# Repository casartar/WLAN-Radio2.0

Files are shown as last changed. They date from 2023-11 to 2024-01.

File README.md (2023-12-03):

# WLAN-Radio2.0

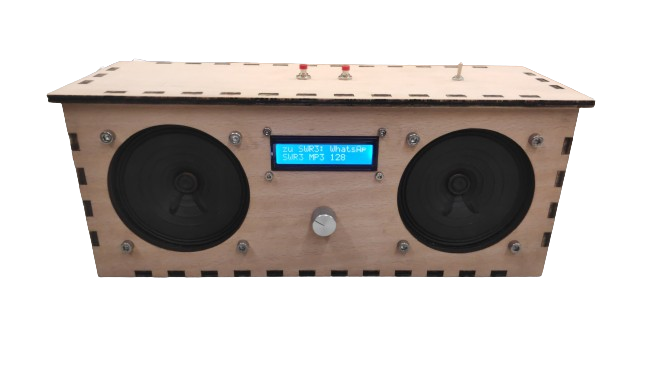
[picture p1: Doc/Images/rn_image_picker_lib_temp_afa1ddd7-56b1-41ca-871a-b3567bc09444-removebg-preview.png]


## 1. Komponenten
TBD

## Testaufbau
### SMD Bestückung
Siehe [ibom](https://github.com/casartar/WLAN-Radio2.0/blob/main/Hardware/WLAN-Radio-HAT/bom/ibom.html)
### THT Bestückung

Buchsenleiste an WLAN-Radio-HAT anlöten. Darauf auchten, dass der Stecker gut auf der Platine aufliegt.

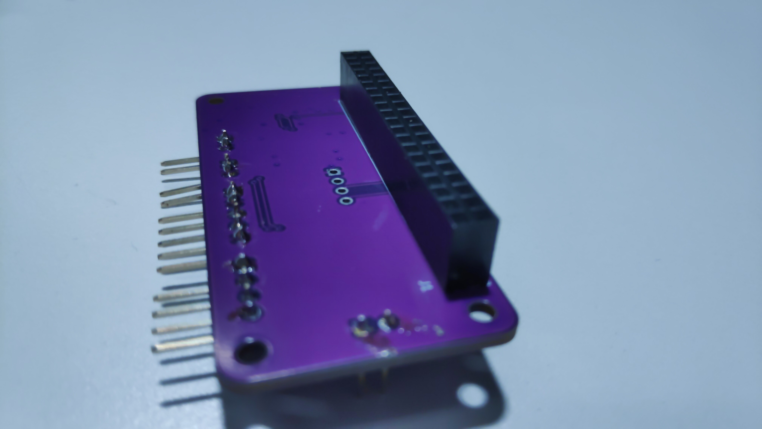
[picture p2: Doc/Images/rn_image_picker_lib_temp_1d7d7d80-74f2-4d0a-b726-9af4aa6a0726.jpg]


Gewinkelte Stiftleisten anlöten.

Aus Gründen für die 5V Spannungsversorgung gerade Stiftleisten verwenden.

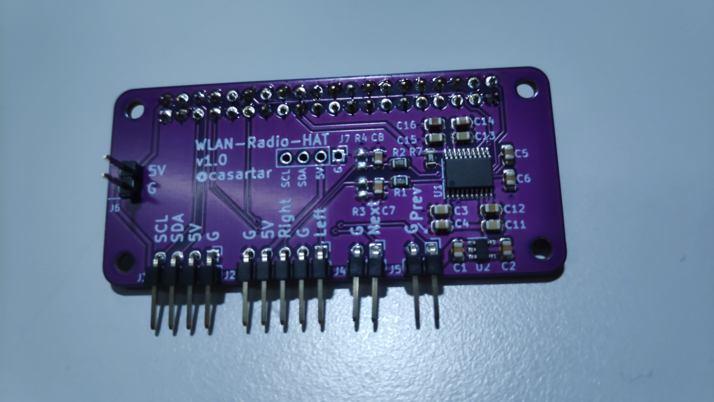
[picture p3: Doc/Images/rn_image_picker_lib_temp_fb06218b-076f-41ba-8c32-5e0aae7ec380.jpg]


Buchsenleiste and LCD anlöten.

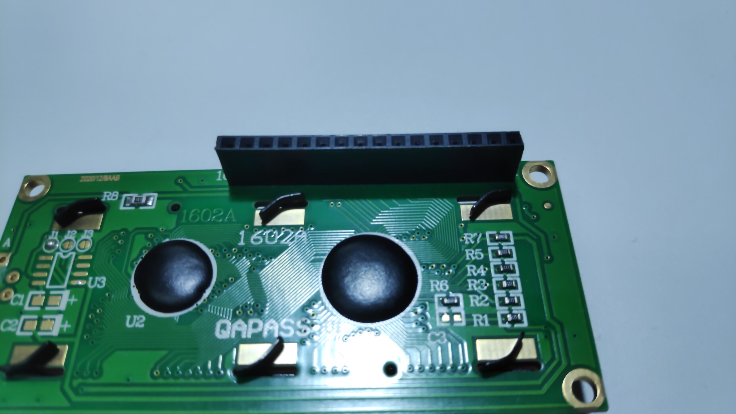
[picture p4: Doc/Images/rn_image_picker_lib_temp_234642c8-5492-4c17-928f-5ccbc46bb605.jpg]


Gewinkelte Stifleisten an Verstärkermodul anlöten.

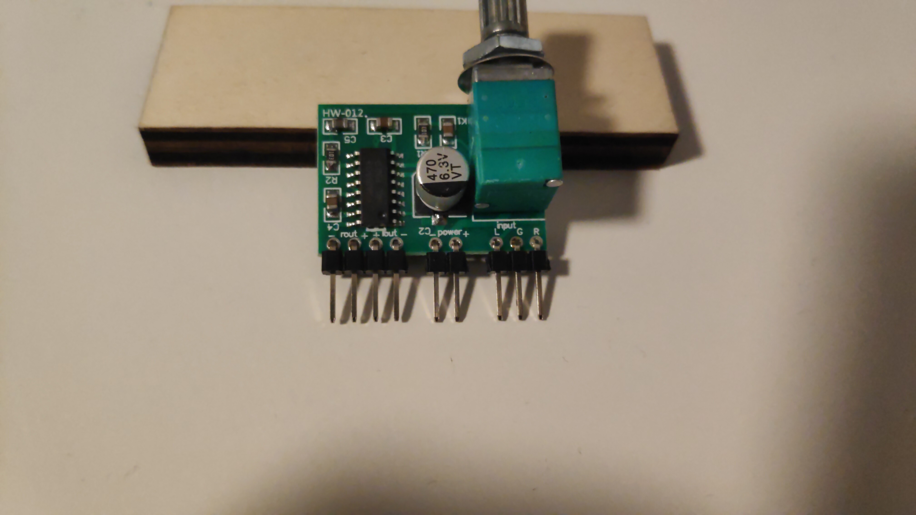
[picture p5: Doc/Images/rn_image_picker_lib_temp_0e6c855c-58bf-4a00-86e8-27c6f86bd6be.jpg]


### Testaufbau

* WLAN-Radio-HAT auf Raspberry Pi Zero W stecken.
* LCD anschließen.
* Verstärker anschließen.
* Lautsprecher an Verstärker anstecken.
* Micro-USB-Kabel an das Raspberry Pi anschließen (PWR IN).

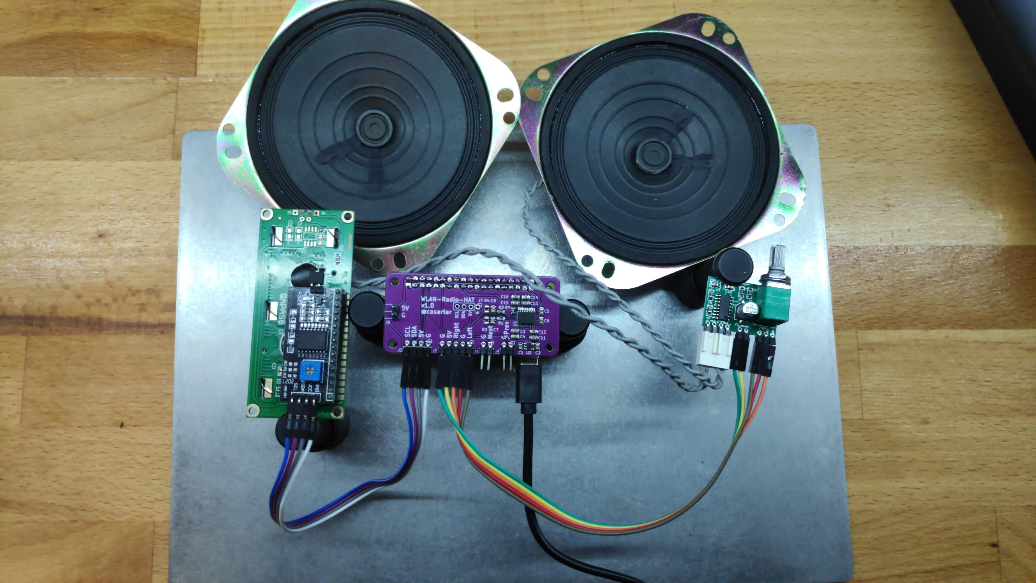
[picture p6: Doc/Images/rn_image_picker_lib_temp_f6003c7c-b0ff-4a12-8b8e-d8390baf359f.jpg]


## Software-Installation

### Erstellen der SD-Karte für den Raspberry Pi mittels Raspberry Pi Imager

Raspberry Pi Imager installieren - https://www.raspberrypi.com/software/ 

Raspberry Pi Imager ausführen.
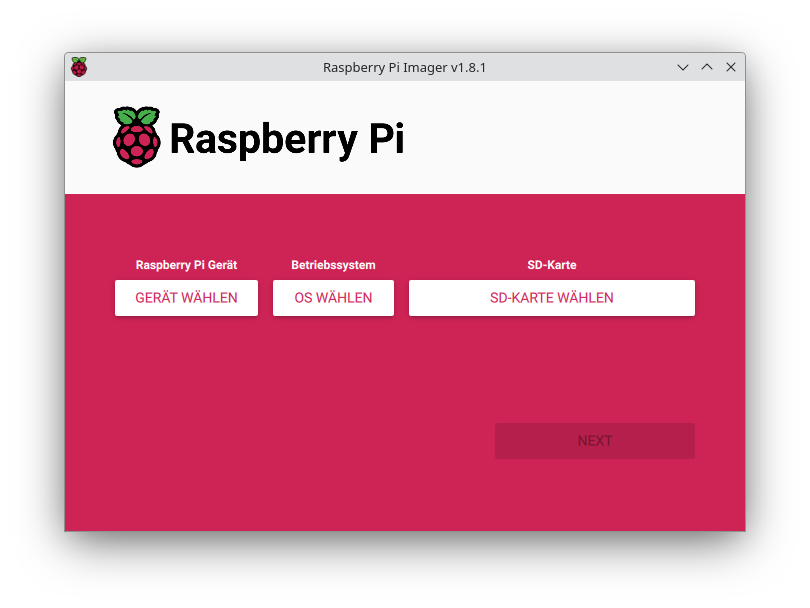
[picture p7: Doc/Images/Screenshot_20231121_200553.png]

Gerät wählen: Raspberry Pi Zero
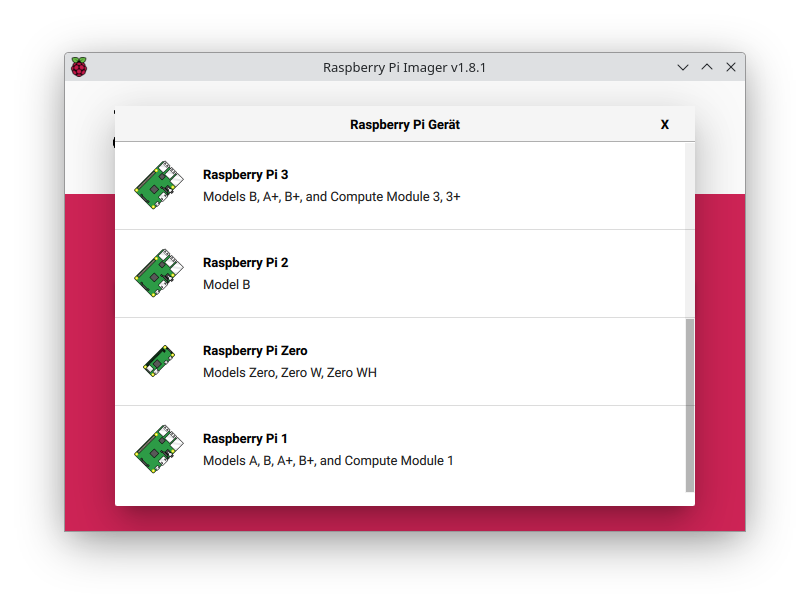
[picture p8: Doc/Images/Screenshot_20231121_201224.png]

Os wählen: Raspberry Pi OS (other)
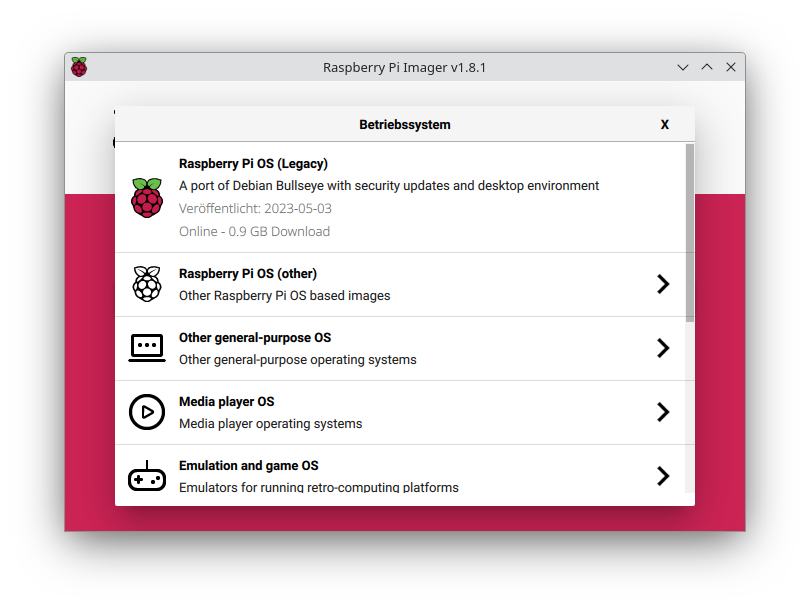
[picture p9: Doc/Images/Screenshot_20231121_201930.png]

Raspberry Pi OS (Legacy) Lite
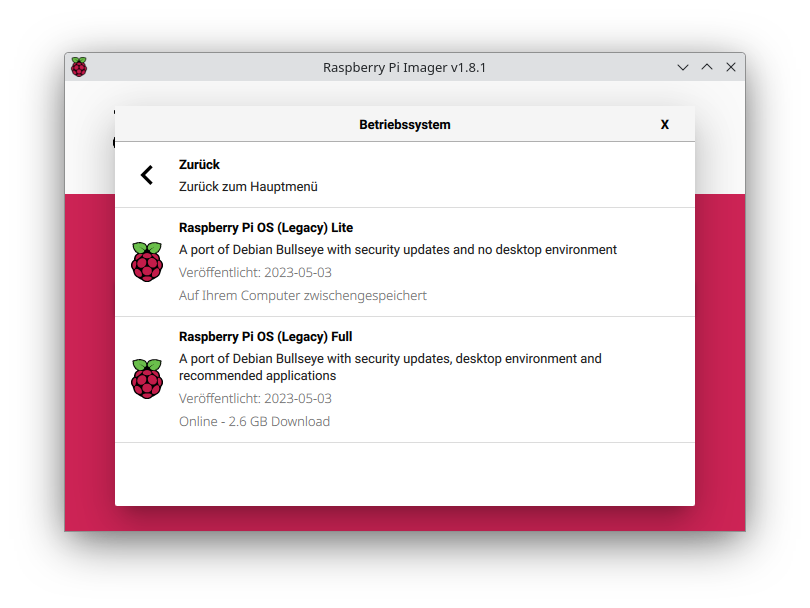
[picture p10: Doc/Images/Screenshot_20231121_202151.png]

SD-Karte wählen.
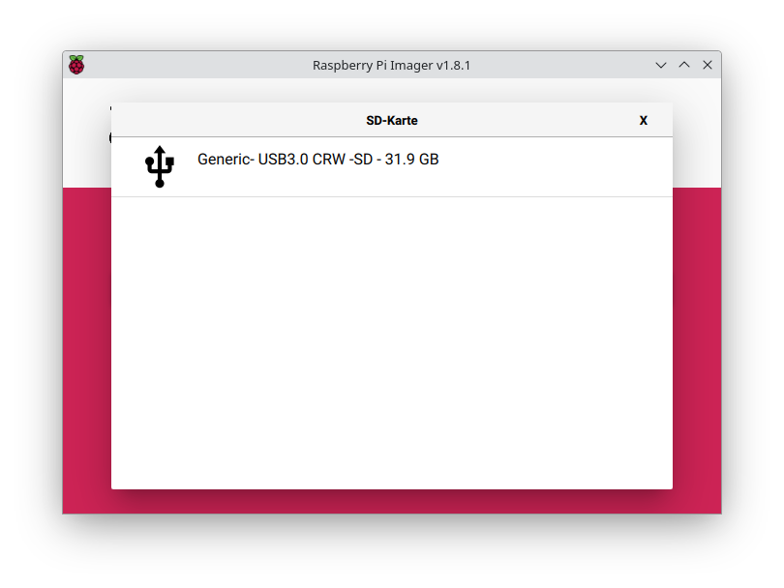
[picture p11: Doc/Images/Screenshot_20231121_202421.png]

Next
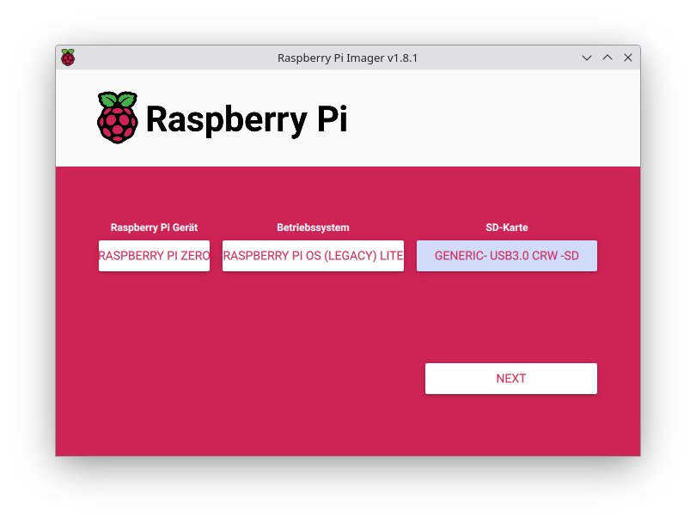
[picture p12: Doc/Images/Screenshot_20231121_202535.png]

Einstellungen bearbeiten.
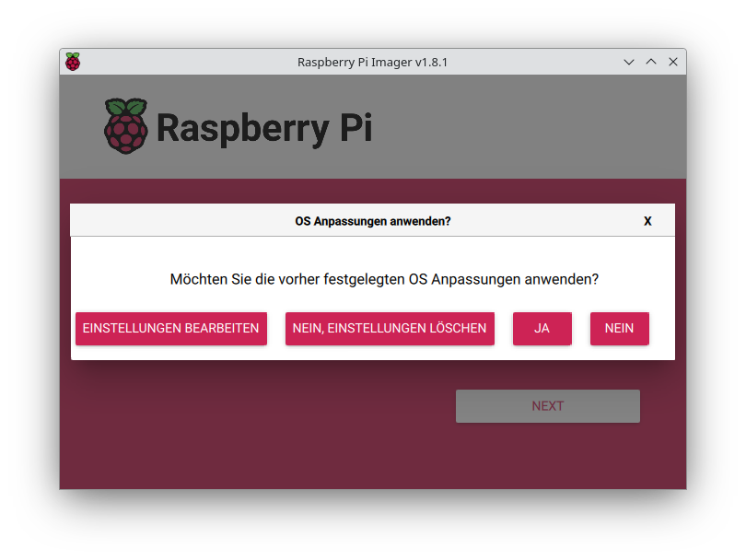
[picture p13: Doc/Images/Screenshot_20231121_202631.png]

* Hostname: individuell benennen.
* Benutzer: "pi"
* Passwort: "raspberry"
* SSID: geheim
* Passwort: geheim

Im Reiter "Dienste" kann man auch gerne seinen Public Key hinterlegen, muss aber nicht sein.
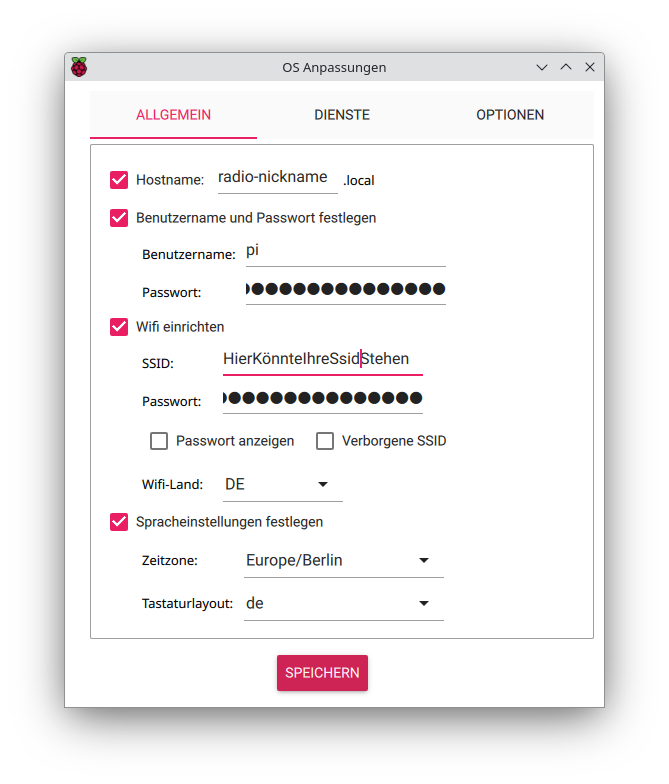
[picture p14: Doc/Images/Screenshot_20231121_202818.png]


Im Reiter "Dienste" SSH aktivieren und "Passwort zur Authentifizierung verwenden" auswählen. Wer weiß was er tut, kann man auch gerne seinen Public Key hinterlegen, muss aber nicht sein.
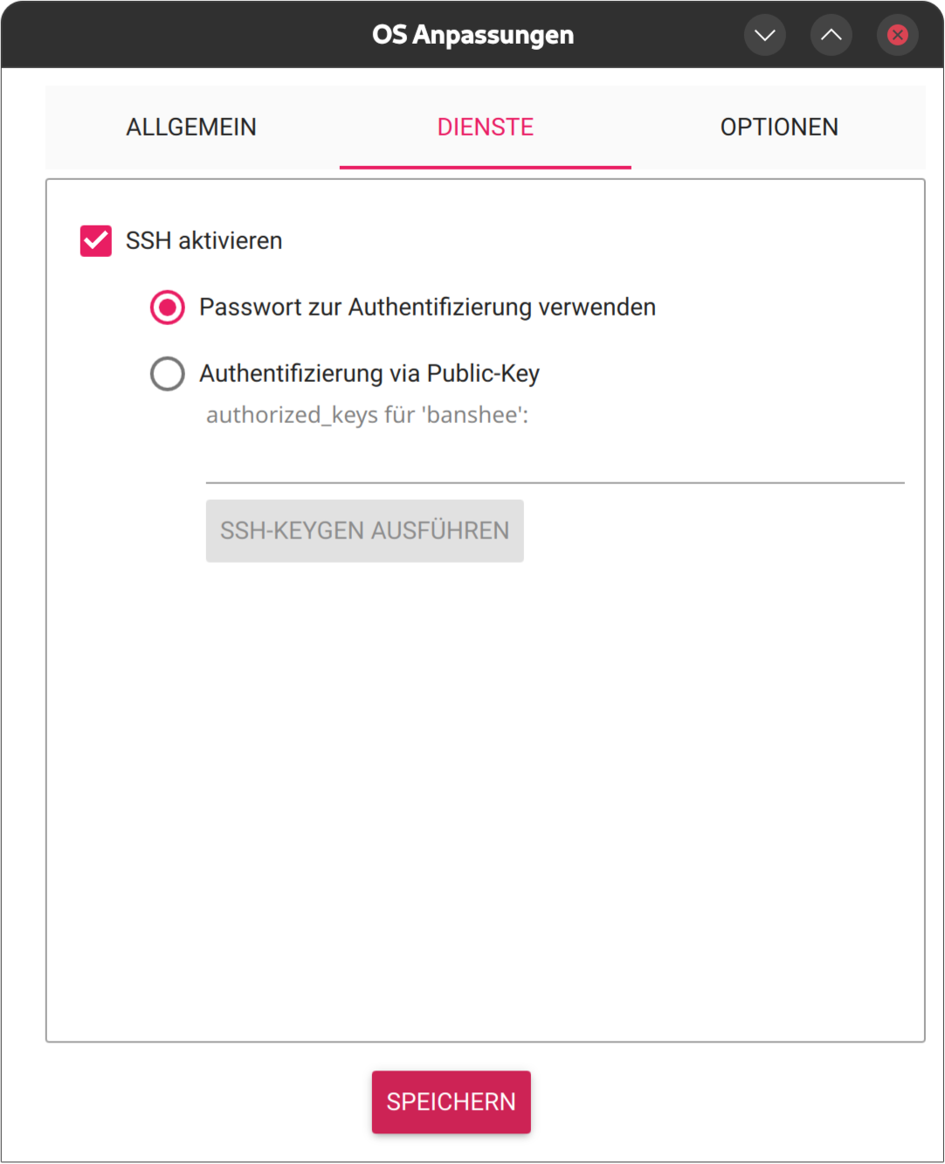
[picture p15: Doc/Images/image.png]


Speichern und Ja wählen und mit Ja bestätigen
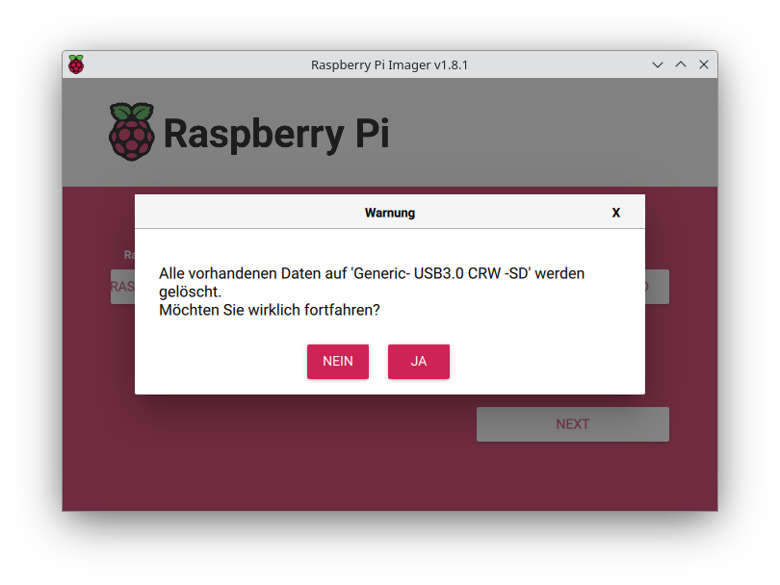
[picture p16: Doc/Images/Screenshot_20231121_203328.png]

SD-Karte wird beschrieben.
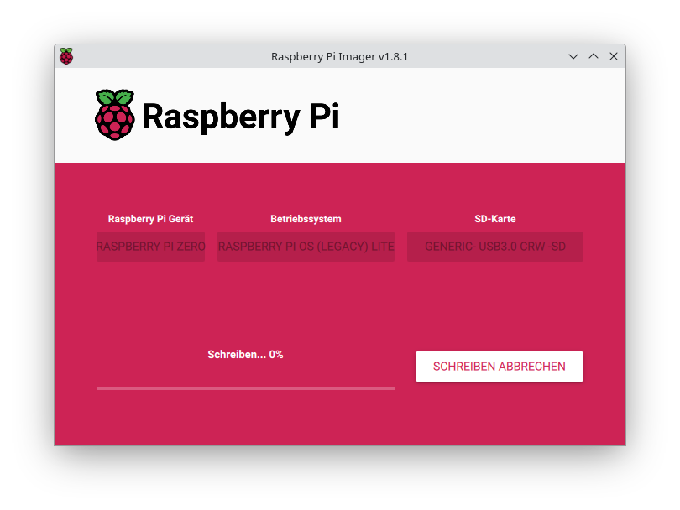
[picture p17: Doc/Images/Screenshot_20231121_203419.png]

SD-Karte ist fertig beschrieben.
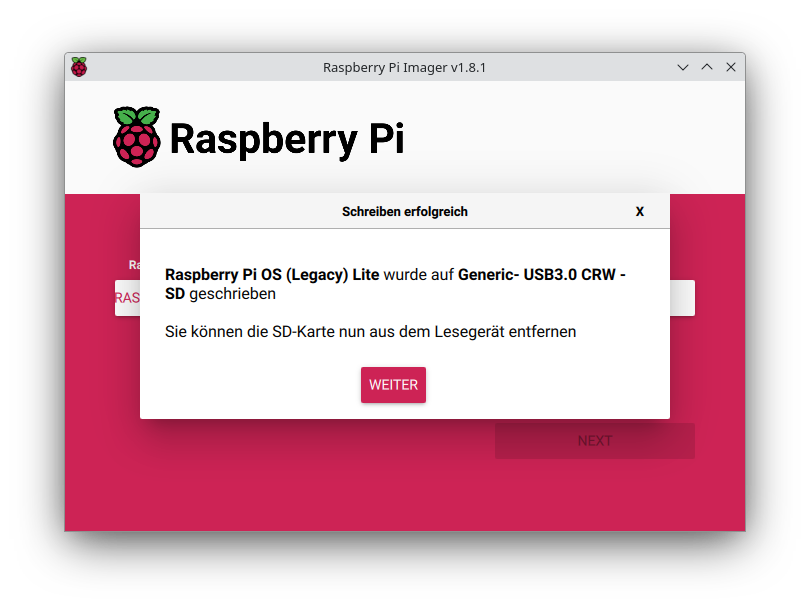
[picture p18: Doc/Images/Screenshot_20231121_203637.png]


SD-Karte in Pi einstecken und Micro-USB-Kabel an Laptop anschließen.
  
### Der erste Start des Pi dauert u.U. mehrere Minuten

### System aktualisieren
IP Adresse herausfinden

Verbinden per ssh, user: pi; passwort wie oben konfiguriert.
Der Befehl funktioniert unter Linux und unter Window in der PowerShell

```
ssh pi@xxx.xxx.xxx.xxx

sudo apt update
sudo apt upgrade
```

### GIT installieren und WLAN-Radio2.0 clonen

```
sudo apt install git
sudo git clone https://github.com/casartar/WLAN-Radio2.0.git
```

### LCD Komponenten installieren und Testen

```
sudo apt install i2c-tools
sudo apt install python3-pip
sudo apt install python3-smbus
pip install RPLCD
```
Wenn pip einen Fehler ausgibt noch mal versuchen mit:
```
pip install RPLCD --break-system-packages
```

/boot/config.txt anpassen mit

```
sudo nano /boot/config.txt
```

Parameter: **dtparam=i2c_arm=on** einkommentieren

Speichern mit Strg+O, Enter und Schließen mit Strg+X.

Neustart

```
sudo reboot
```

Verbinden per ssh

```
sudo i2cdetect -y 1
cd ~/WLAN-Radio2.0/Software
python3 lcd_test.py
```

Auf dem LCD sollte jetzt **"WLAN Radio"** und **"1234567890abcdef"** angezeigt werden.

### Audio Komponenten installieren und Testen

/boot/config.txt anpassen mit

```
sudo nano /boot/config.txt
```

Am Ende der Datei hinzufügen: **dtoverlay=hifiberry-dac**
Zeile auskommentieren (Raute vorne dran) **#dtparam=audio=on**
Zeile auskommentieren (Raute vorne dran)  **#dtoverlay=vc4-kms-v3d**

Speichern mit Strg+O, Enter und Schließen mit Strg+X.

Neustart

```
sudo reboot
```

Verbinden per ssh

Testen mit:

```
speaker-test -t wav -c 2
```

Es sollte "Front Left" und "Front Right" aus den entsprechenden Lautsprechern ertönen.

Mit Strg + C kann die Ausgabe abbrechen.

### MPD und MPC einrichten (Music Player Daemon, Music Player Client)

```
sudo apt install mpd
sudo apt install mpc
```

/etc/mpd.conf anpassen mit

```
sudo nano /etc/mpd.conf
```

Zeile ändern von
```
playlist_directory   /var/lib/mpd/playlists
```
in
```
playlist_directory   /home/pi/Playlists/
```

und 

```
audio_output {
#       type            "alsa"
#       name            "My ALSA Device"
#       device          "hw:0,0"        # optional
#       mixer_type      "hardware"      # optional
#       mixer_device    "default"       # optional
#       mixer_control   "PCM"           # optional
#       mixer_index     "0"             # optional
}
```
ändern in 

```
audio_output { 
        type            "alsa" 
        name            "sysdefault:CARD=sndrpihifiberry" 
        mixer_type      "software" 
}
```

Speichern mit Strg+O, Enter und Schließen mit Strg+X.

Das Verzeichnis anlegen: 
```
mkdir ~/Playlists
```

Default Playlist aus dem Repo in dieses Verzeichnis kopieren: 

```
cp ~/WLAN-Radio2.0/Playlist/Playlist.m3u Playlists/
```

mpd.service neu starten: 
```
sudo systemctl restart mpd
```
Testen ob Radio abgespielt wird
```
mpc load Playlist
mpc play
mpc next
mpc status
mpc pause
```
Wenn nach mpc load P Playlist nicht autovervollständigt wird, muss evtl. in der mpd.conf der User von mpd zu pi geändert werden.

MPD Library installieren
```
sudo apt install python3-mpd
```
MPD Test Script ausführen
```
cd ~/WLAN-Radio2.0/Software
python3 mpd_test.py
```

Es sollte ein Sender abgespielt werden.

Mit Strg + C wird der test beendet.

### Radio Testen

```
cd ~/WLAN-Radio2.0/Software
python3 radio_test.py
```

Mit der Pinzette die beiden Pins für Next respektive Previous kurzschließen und prüfen, ob ein anderer Sender abgespielt wird.

### Weitere WLAN-Zugangsdaten hinzufügen

```
sudo nano /etc/wpa_supplicant/wpa_supplicant.conf
```
Die konfiguration sollte in etwa so aussehen:

```
ctrl_interface=DIR=/var/run/wpa_supplicant GROUP=netdev
update_config=1

network={
        ssid="HierKönnteIhreSsidStehen"
        psk=e04000a6ccb88f7ac28bd18ed807fdb820ac8524dbc6f50d4bfe2d788c3609fd
}
```

Das muss erweitert werden zu:

```
ctrl_interface=DIR=/var/run/wpa_supplicant GROUP=netdev
update_config=1

network={
        ssid="HierKönnteIhreSsidStehen"
        psk=e04000a6ccb88f7ac28bd18ed807fdb820ac8524dbc6f50d4bfe2d788c3609fd
}
network={
        ssid="AndereSsid"
        psk="pazzzW0rd"
}
```

Speichern mit Strg+O, Enter und Schließen mit Strg+X.

### Autostart

```
sudo cp ~/WLAN-Radio2.0/Config/wlan-radio.service /etc/systemd/system/
sudo chmod 640 /etc/systemd/system/wlan-radio.service
systemctl status wlan-radio
sudo systemctl daemon-reload
sudo systemctl enable wlan-radio
sudo systemctl start wlan-radio
sudo systemctl status wlan-radio
```

## Gehäuse Lasern

Benötigt wird die Datei Case_with_custom_cutouts_6mm.svg

Das Gehäuse wird aus Buche Sperrholzplatten 6mm gelasert. 
Startingpoint sind 80% Leistung und 20 mm/s Geschwindigkeit.

Nach dem Lasern sollten die Schnittkanten mit Schmiergelpapier bearbeitet werden, da das Holz sehr nach verbrannt riecht.

Ob man das Holz weiter bearbeiten, also einölen oder lackieren möchte, darf jeder selbst entscheiden.

## Fräsarbeiten

Die Bedienelemente müssen im Holz versenkt werden, da die Gewinde für 6 mm Holz zu kurz sind.
Für die Vertiefungen wird mit der Oberfräse 3 mm abgefäst.

Wo gefäst werden muss, ist in der Datei Deepenings.svg rot markiert.

ACHTUNG! Die Zeichung ist die Sicht von Außen auf das Radio, die Vertiefungen sind aber innen. Beim Display muss also gespiegelt ausgefräßt werden.

Am besten steckt man die Bauteile in die Aussparungen und zeichnet mit dem Bleistift an, wo gefräßt werden soll.

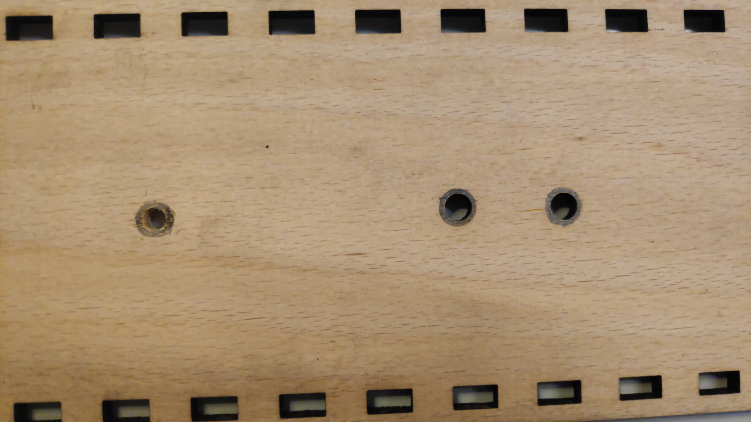
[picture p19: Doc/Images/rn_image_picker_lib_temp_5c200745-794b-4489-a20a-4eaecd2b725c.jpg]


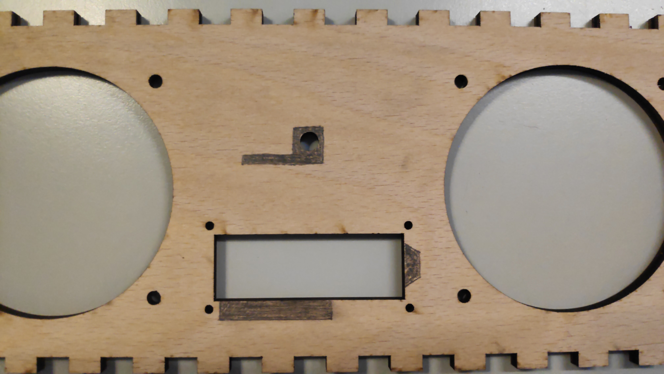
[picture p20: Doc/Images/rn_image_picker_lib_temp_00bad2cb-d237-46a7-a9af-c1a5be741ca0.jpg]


## Einbau der Elektronik

### Rückwand (USB-C + Pi)
Vor dem einbau der USB-C Buchse werden an die Leitungen Dupont Buchsen gecrimpt.

Um den Pi zu montieren, müssen von außen vier Zylinderkopfschrauben M2,5 mit Länge 8 mm gesteckt werden.
Von innen werden Stehbolzen M2,5 (Länge relativ egal) mit Innen- und Außenewinde auf die Schrauben augeschraubt. Darauf wird der Pi gesteckt. Dann werden wieder vier Stehbolte mit Innen und Außengewinde aufgeschraubt. Länge 11 mm. Dann kommt der HAT und M2,5 Muttern.

### Deckel

An die beiden Taster werden zweipolige Stiftleisten gelötet und dann verschraubt.

Beim Schalter werden an zwei benachbarte Kontakt je eine zweipolige Stiftleiste gelötet.

### Front

Vorne werden die Lautsprecher mit 8 M5 Zylinderkopfschrauben mit Länge 10 mm und entsprechenden Muttern befestigt.

Für das LCD werden 4 M3 Zylinderkopfschrauben mit Länge 12 mm und entsprechende Muttern benötigt.

Der Verstärker wird mit den beiligenden Utensilien befestigt.

## Zusammenleimen

Man benutze viele viele Schraubzwingen und sanfte Gewalt beim Zusammenstecken.

Der Boden wird nicht verleimt, sondern nur gesteckt. Sollte er nicht halten, muss man sich was schlaues überlegen, dass er es doch tut.

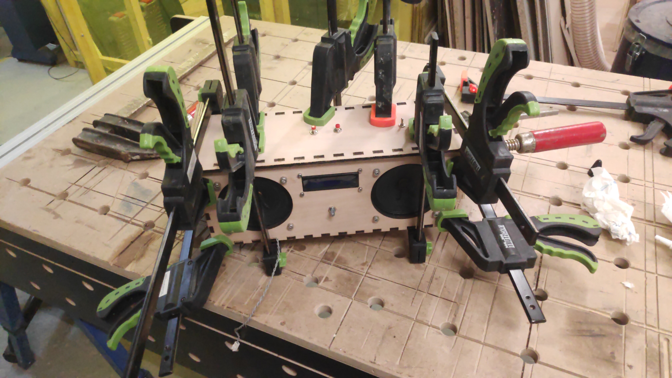
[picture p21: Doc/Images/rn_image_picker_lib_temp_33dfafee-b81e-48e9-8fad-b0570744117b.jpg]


## Verkabelung

Wenn alles mit rechten Dingen zugegangen ist, sollte jetzt alles mit ordinären Jumperkabeln zu verbinden sein. 

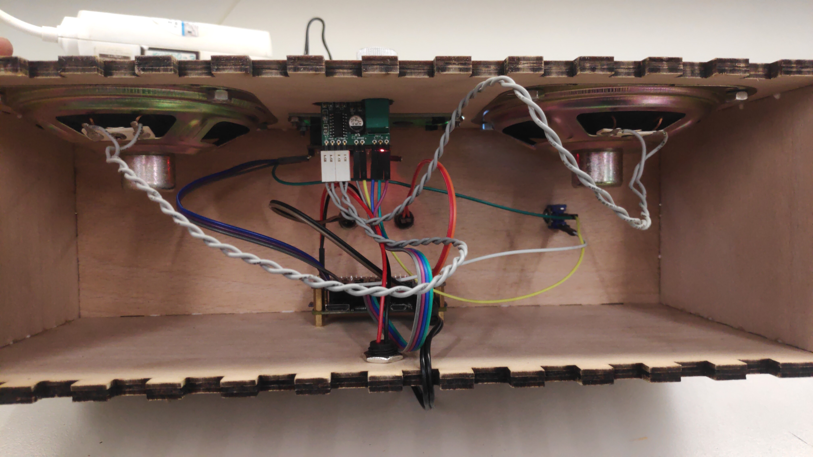
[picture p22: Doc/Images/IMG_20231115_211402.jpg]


1. Die gecrimpten Buchsen an der USB-C buchse werden auf die Spannungsversorgungspins auf dem HAT gesteckt.
2. Der mit 5V markierte Pin des LCD-Anschlusses wird mit einem Pin am An/Aus-Schalter verbunden.
3. Vom An/Ausschalter werden zwei weitere Jumperkabel (vom anderen Anschluss) an das LCD und den Verstärker geführt.
4. Je zwei Leitungen werden für die Taster benötigt.
5. Den Rest der Verkabelung für LCD und Verstärker, wie im Testaufbau.

Wenn man jetzt das Netzteil einsteckt, sollte nach eineiger Zeit das Radio ertönen.

## Senderliste bearbeiten

Per SSH verbinden:

```
ssh pi@xxx.xxx.xxx.xxx
cd ~/Playlists
nano Playlist.m3u
```

Hier neue Webstreams hinzufügen.

https://streamurl.link/ scheint eine ganz gute Quelle für URLs zu sein.

Speichern mit Strg+O, Enter und Schließen mit Strg+X.

Das WLAN-Radio neu starten. Dabei wird die Playlist neu eingelesen.

```
sudo systemctl restart wlan-radio
```

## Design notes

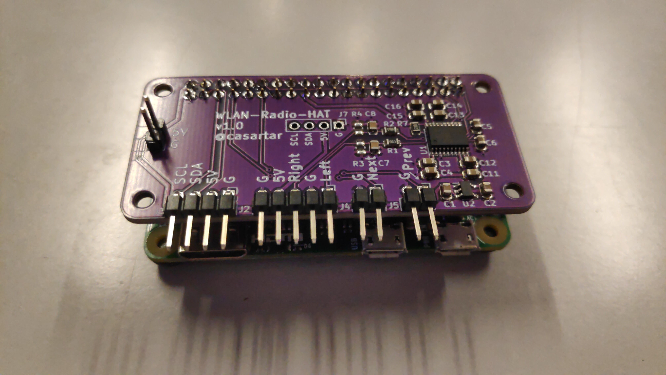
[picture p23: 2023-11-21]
Doc/Images/rn_image_picker_lib_temp_ceb98b77-e183-4f8b-b329-764020756eba.jpg

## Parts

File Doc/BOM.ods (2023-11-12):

Platine JLCPCB
PCB |  |  | 1 | https://github.com/casartar/WLAN-Radio2.0/tree/main/Hardware/WLAN-Radio-HAT
Bauteile LCSC
Codec | PCM5100APWR | LCSC#: C131154 | 1 | https://www.lcsc.com/product-detail/_Texas-Instruments-_C131154.html
Linearregler | ADP150AUJZ-3.3-R7 | LCSC#: C29149 | 1 | https://www.lcsc.com/product-detail/_Analog-Devices-_C29149.html
100nF | CL21A106KPFNNNE | LCSC#: C17024 | 4 | https://www.lcsc.com/product-detail/_Samsung-Electro-Mechanics-_C17024.html
2,2µF | CL21B225KAFNNNE | LCSC#: C19110 | 2 | https://www.lcsc.com/product-detail/_Samsung-Electro-Mechanics-_C19110.html
2,2nF | 0805B222K500NT | LCSC#: C36576 | 2 | https://www.lcsc.com/product-detail/_FH-Guangdong-Fenghua-Advanced-Tech-_C36576.html
470R | 0805W8F4700T5E | LCSC#: C17710 | 2 | https://www.lcsc.com/product-detail/_UNI-ROYAL-Uniroyal-Elec-_C17710.html
10k | 0805W8F1002T5E | LCSC#: C17414 | 1 | https://www.lcsc.com/product-detail/_UNI-ROYAL-Uniroyal-Elec-_C17414.html
Stiftleisten | ZX-PZ2.54-1-40PWZ | LCSC#: C7501294 | 1 | https://www.lcsc.com/product-detail/Pin-Headers_Megastar-ZX-PZ2-54-1-40PWZ_C7501294.html
Berrybase
Raspberry Pi | Raspberry Pi Zero WH | Artikel-Nr: RPIZ-WH | 1 | https://www.berrybase.de/raspberry-pi-zero-wh
SD-Card | SanDisk Ultra microSDHC A1 120MB/s Class 10 Speicherkarte + Adapter 32GB | Artikel-Nr: 619659184155 | 1 | https://www.berrybase.de/sandisk-ultra-microsdhc-a1-120mb/s-class-10-speicherkarte-adapter-32gb
Netzteil | offizielles Raspberry Pi USB-C Netzteil 5,1V / 3,0A, EU, schwarz | Artikel-Nr: RPI4NT3AB | 1 | https://www.berrybase.de/offizielles-raspberry-pi-usb-c-netzteil-5-1v/3-0a-eu-schwarz
Jumperkabel kurz | 40pin Jumper / Dupont Kabel Female Female trennbar 0,20 m | Artikel-Nr: DUPK-40-FF-20 | 1 | https://www.berrybase.de/40pin-jumper/dupont-kabel-female-female-trennbar
Jumperkabel lang | 40pin Jumper / Dupont Kabel Female Female trennbar 0,50 m | Artikel-Nr: DUPK-40-FF-50 | 1 | https://www.berrybase.de/40pin-jumper/dupont-kabel-female-female-trennbar
Pollin
Lautsprecher | Lautsprecher, REGAL, 8 Ohm, 3W | 94-641551 | 1 | https://www.pollin.de/p/lautsprecher-regal-8-ohm-3w-2-stueck-641551
Amazon
Drehknopf | sourcing map 10St Potentiometerknopf Rändelwelle Aluminium Drehknopf Lautstärkeregler Schwarz 10mmx15mm 6mm Welle |  | 1/10 | https://www.amazon.de/dp/B08214YZDS?psc=1&ref=ppx_yo2ov_dt_b_product_details
M2,5 Schrauben | sourcing map M2,5x 12mm Vollgewinde Innensechskantschraube Schraube Silberton 50Stk. |  | 4/50 | https://www.amazon.de/dp/B01D9SF8FG?psc=1&ref=ppx_yo2ov_dt_b_product_details
Buchsenleisten | Akozon Stift Vorsatz Verbindungsstück 5 stücke 2 x 20 Pins 2,54 mt Pitch Weibliche Zweireihige Kurze Pin Header für Raspberry Pi |  | 1/5 | https://www.amazon.de/dp/B07GH1L92Q?psc=1&ref=ppx_yo2ov_dt_b_product_details
M2,5 Abstandbolzen | 486Stk M2.5 Abstandshalter Hex Distanzhülsen PCB Board/Platinen Männlich Weiblich Gewinde Abstandsbolzen Schrauben Muttern Messing Hex Schraubenmutter Sortiment Kit für Platine Raspberry Pi Mainboard |  | 4/44 | https://www.amazon.de/dp/B0C1FY87PY?ref=ppx_yo2ov_dt_b_product_details&th=1
M2,5 x 11 Abstandbolzen | MMOBIEL M2.5 Abstandshalter für Raspberry Pi - Sechskant/Messing/Abstandszylinder, Schrauben, Muttern für Minicomputer-Leiterplatten - 11 mm Gehäuse und 6 mm Schraube - Inkl. Schraubendreher |  | 4/24 | https://www.amazon.de/dp/B08M3PN7BT?psc=1&ref=ppx_yo2ov_dt_b_product_details
Verstärker | AZDelivery 5 x PAM8403 digitaler Mini Audio Verstärker 2x 3 Watt DC 5V Leistungsverstärkerplatine mit Potentiometer für DIY Lautsprecher und Kopfhörer inklusive Ebook |  | 1/5 | https://www.amazon.de/dp/B09PL77NCY?ref=ppx_yo2ov_dt_b_product_details&th=1
LCD blau | AZDelivery 5 x HD44780 16x2 LCD Modul Display Bundle mit I2C Schnittstelle 2x16 Zeichen kompatibel mit Arduino und Raspberry Pi inklusive E-Book! (mit Blauem Hintergrund und Weißen Zeichen) |  | 1/5 | https://www.amazon.de/dp/B07V29SSVD?ref=ppx_yo2ov_dt_b_product_details&th=1
oder LCD grün | AZDelivery 5 x HD44780 16x2 LCD Modul Display Bundle mit I2C Schnittstelle 2x16 Zeichen kompatibel mit Arduino inklusive E-Book! (mit Grünem Hintergrund und Schwarzen Zeichen) |  | 1/5 | https://www.amazon.de/dp/B079SW5SYD?psc=1&ref=ppx_yo2ov_dt_b_product_details
USB-C Verschraubung | Greluma 5 Stk Wasserdichte Typ C Buchse, USB C Einbausteckverbinder mit Mutter Sicherungsplatte |  | 1/5 | https://www.amazon.de/dp/B0BX37L2V3?ref=ppx_yo2ov_dt_b_product_details&th=1
Schalter | QWORK 20Stk Mini Kippschalter SPST AC 125V 6A ON-ON 3 Pins 2 Position für Auto Arduino LKW Boot (MTS102) |  | 1/10 | https://www.amazon.de/dp/B0B56S4F1X?psc=1&ref=ppx_yo2ov_dt_b_product_details
Taster | Gebildet 24 Stücke 7mm Mini Momentan Druckknopf, SPST EIN-AUS 3V-6V-12V-24V-230V/1A, 2 Pin Runder Flachknopf-Drück Knöpfe für Modelleisenbahn-Hobby |  | 2/24 | https://www.amazon.de/dp/B07XRKN3F3?ref=ppx_yo2ov_dt_b_product_details&th=1
Sonstiges
M5 Schraube |  |  | 4
M5 Mutter |  |  | 4
M3 Schraube |  |  | 4
M3 Mutter |  |  | 4
Stifleiste gerade

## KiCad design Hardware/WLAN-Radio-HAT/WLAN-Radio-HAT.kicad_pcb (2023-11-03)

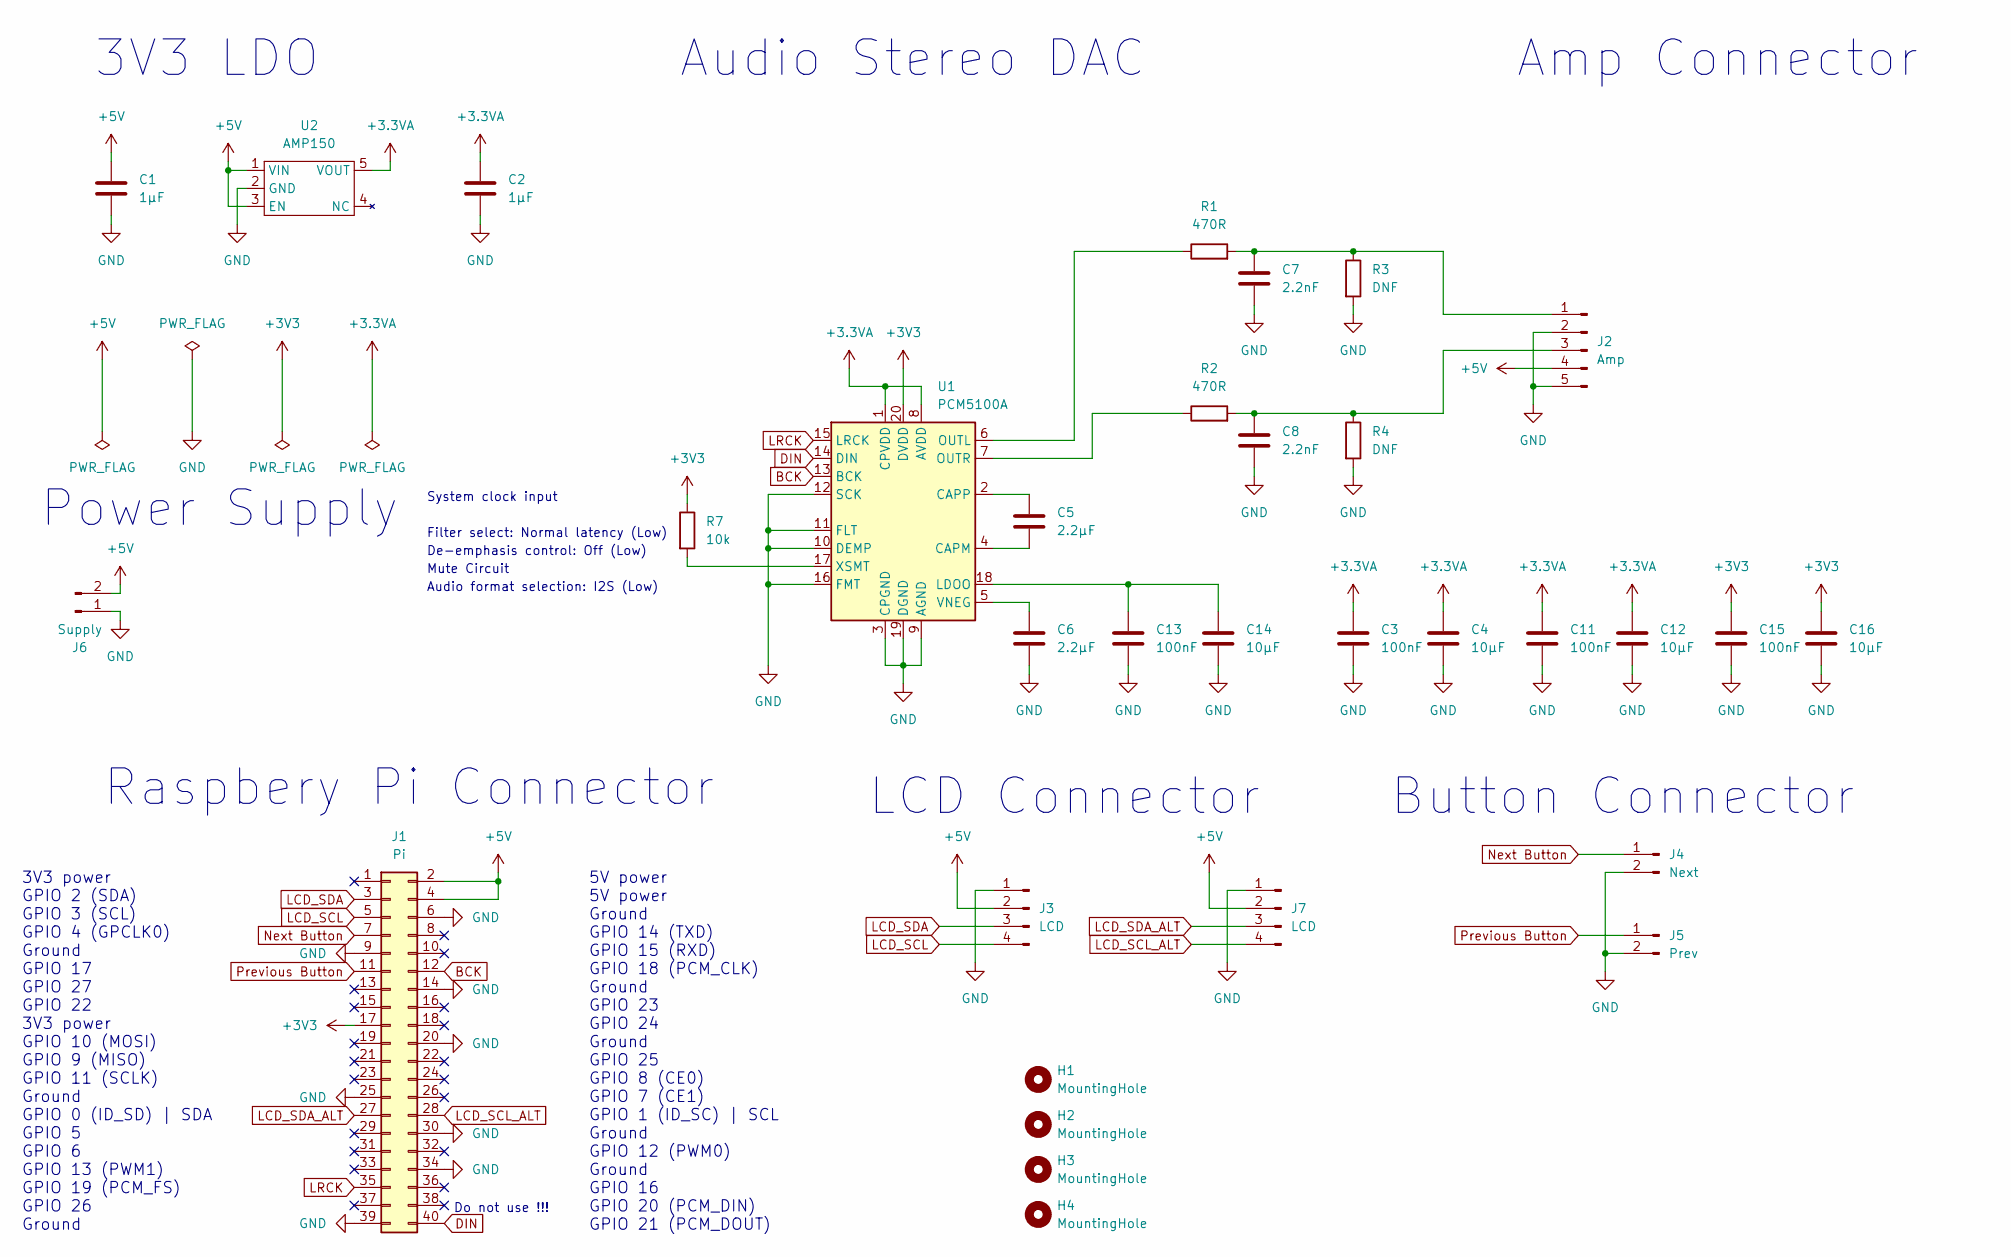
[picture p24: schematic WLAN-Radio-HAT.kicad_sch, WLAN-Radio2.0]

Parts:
C1, C2: 1µF; C_0805_2012Metric
C3, C11, C13, C15: 100nF; C_0805_2012Metric
C4, C12, C14, C16: 10µF; C_0805_2012Metric
C5, C6: 2.2µF; C_0805_2012Metric
C7, C8: 2.2nF; C_0805_2012Metric
H1, H2, H3, H4: MountingHole; MountingHole_2.7mm_M2.5
J1: Pi; PinSocket_2x20_P2.54mm_Vertical
J2: Amp; PinHeader_1x05_P2.54mm_Horizontal
J3: LCD; PinHeader_1x04_P2.54mm_Horizontal
J4: Next; PinHeader_1x02_P2.54mm_Horizontal
J5: Prev; PinHeader_1x02_P2.54mm_Horizontal
J6: Supply; PinHeader_1x02_P2.54mm_Horizontal
J7: LCD; PinHeader_1x04_P2.54mm_Vertical
R1, R2: 470R; R_0805_2012Metric
R3, R4: DNF; R_0805_2012Metric
R7: 10k; R_0805_2012Metric
U1: PCM5100A; TSSOP-20_4.4x6.5mm_P0.65mm
U2: AMP150; TSOT-23-5

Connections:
+3.3VA: C2.1, C3.1, C4.1, C11.1, C12.1, U1.1 (CPVDD), U1.8 (AVDD), U2.5 (VOUT)
+3V3: C15.1, C16.1, J1.17, R7.1, U1.20 (DVDD)
+5V: C1.1, J1.2, J1.4, J2.4, J3.2, J6.2, J7.2, U2.1 (VIN), U2.3 (EN)
BCK: J1.12, U1.13 (BCK)
DIN: J1.40, U1.14 (DIN)
GND: C1.2, C2.2, C3.2, C4.2, C6.2, C7.2, C8.2, C11.2, C12.2, C13.2, C14.2, C15.2, C16.2, J1.6, J1.9, J1.14, J1.20, J1.25, J1.30, J1.34, J1.39, J2.2, J2.5, J3.1, J4.2, J5.2, J6.1, J7.1, R3.2, R4.2, U1.3 (CPGND), U1.9 (AGND), U1.10 (DEMP), U1.11 (FLT), U1.12 (SCK), U1.16 (FMT), U1.19 (DGND), U2.2 (GND)
LCD_SCL: J1.5, J3.4
LCD_SCL_ALT: J1.28, J7.4
LCD_SDA: J1.3, J3.3
LCD_SDA_ALT: J1.27, J7.3
LRCK: J1.35, U1.15 (LRCK)
unnamed: C7.1, J2.1, R1.2, R3.1
unnamed: C8.1, J2.3, R2.2, R4.1
unnamed: C5.2, U1.4 (CAPM)
unnamed: C5.1, U1.2 (CAPP)
unnamed: C13.1, C14.1, U1.18 (LDOO)
unnamed: R1.1, U1.6 (OUTL)
unnamed: R2.1, U1.7 (OUTR)
unnamed: C6.1, U1.5 (VNEG)
unnamed: R7.2, U1.17 (XSMT)
Next Button: J1.7, J4.1
Previous Button: J1.11, J5.1

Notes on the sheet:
Mute Circuit
De-emphasis control: Off (Low)
Do not use !!!
Filter select: Normal latency (Low)
5V power 5V power Ground GPIO 14 (TXD) GPIO 15 (RXD) GPIO 18 (PCM_CLK) Ground GPIO 23 GPIO 24 Ground GPIO 25 GPIO 8 (CE0) GPIO 7 (CE1) GPIO 1 (ID_SC) | SCL Ground GPIO 12 (PWM0) Ground GPIO 16 GPIO 20 (PCM_DIN) GPIO 21 (PCM_DOUT)
3V3 LDO
LCD Connector
Power Supply
Audio format selection: I2S (Low)
3V3 power GPIO 2 (SDA) GPIO 3 (SCL) GPIO 4 (GPCLK0) Ground GPIO 17 GPIO 27 GPIO 22 3V3 power GPIO 10 (MOSI) GPIO 9 (MISO) GPIO 11 (SCLK) Ground GPIO 0 (ID_SD) | SDA GPIO 5 GPIO 6 GPIO 13 (PWM1) GPIO 19 (PCM_FS) GPIO 26 Ground
Amp Connector
Audio Stereo DAC
System clock input
Raspbery Pi Connector
Button Connector

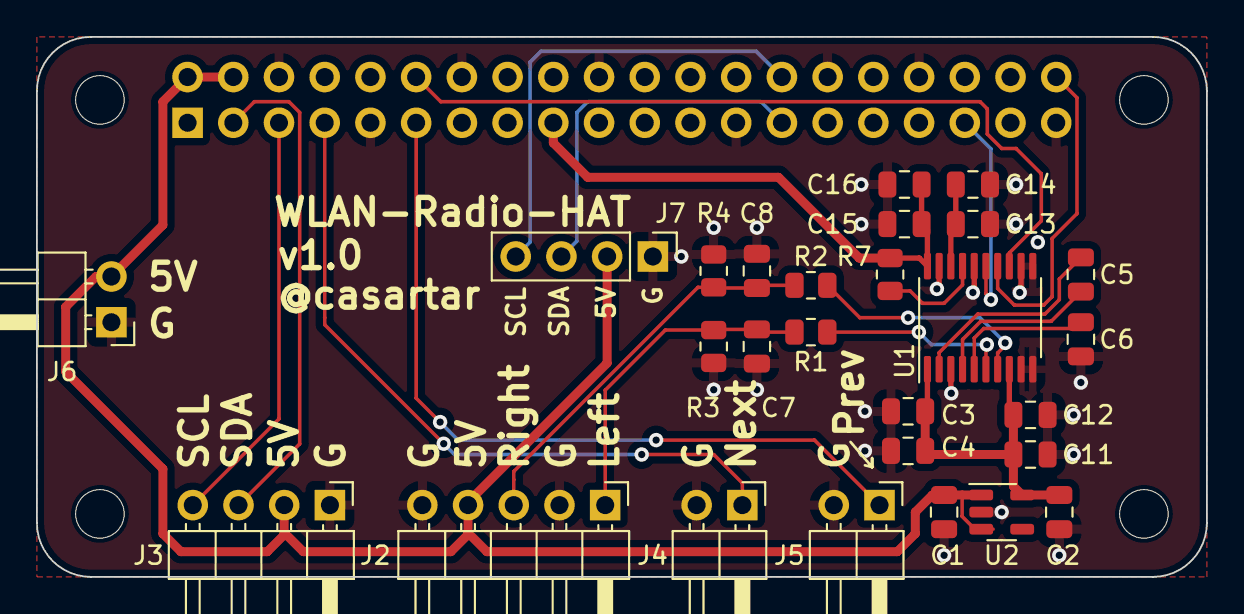
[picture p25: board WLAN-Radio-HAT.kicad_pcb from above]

Board: 2 copper layers, 65.0 x 30.0 mm, 32 parts (1 on the bottom side), 22 nets.

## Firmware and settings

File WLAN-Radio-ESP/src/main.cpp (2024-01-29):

/*
 * ESP-Webradio
 * Following Parts:
 * - audio          : streaming and decoding audio data
 * - lcdisplay      : show station data an LCD
 * - rotary         : initialize and handle choosing senders
 * - senderlist     : senderlist by flash-values - or, if not present, by defaults
 * - senderconfig   : asynchronus webinterface to store sendernames und -urls
 *   senderconf.h   : html-template for above
 * - wlanconfig     : seperate program to get WLAN-config per webinterface
 *   wlanconf.h     : html-template for above
 *   
 *   Used libraries (included in their parts): 
 *   - ESPwebRadio  : Preferences.h
 *   - audio        : ESP8266audio (AudioFileSourceICYStream.h, AudioFileSourceBuffer.h, AudioGeneratorMP3.h, AudioOutputI2S.h)
 *   - lcdisplay    : LiquidCrystal_I2C.h
 *   - rotary       : AiEsp32RotaryEncoder.h
 *   - senderconfig : ESPAsyncWebServer.h, Preferences.h
 *   - wlanconfig   : WiFi.h, Preferences.h, ESPAsyncWebServer.h
 */

#include "senderlist.h"
#include "main.h"
#include "audio.h"
#include "rotary.h"
#include "lcdisplay.h"
#include "wlanconf.h"
#include "wlanconfig.h"
#include "senderconfig.h"

//station list (stations can now be modified by webinterface)
Station stationlist[STATIONS];

//instances of prefernces
Preferences pref;
Preferences sender;

//global variables
uint8_t curStation = 0;   //index for current selected station in stationlist
uint8_t actStation = 0;   //index for current station in station list used for streaming 
uint32_t lastchange = 0;  //time of last selection change

//setup
void setup() {
  Serial.begin(115200);
  delay(1000);
  
  // -------------------
  setup_senderList();
  setup_audio();
  setup_rotary();
  setup_lcdisplay();
  //init WiFi
  Serial.println("Connecting to WiFi");
  while (!makeWLAN()) {
    Serial.println("Cannot connect :(");
    delay(1000);
  }
  Serial.println("Connected");
  setup_senderConfig();
  // -------------------

  //set current station to 0
  curStation = 0;
  //start preferences instance
  pref.begin("radio", false);
  //set current station to saved value if available
  if (pref.isKey("station")) curStation = pref.getUShort("station");
  //set active station to current station 
  //show on display and start streaming
  actStation = curStation;
  showStation();
  startUrl();
}

// main loop
void loop() {
  //check if stream has ended normally not on ICY streams
  if (!loop_audio()) {
    Serial.printf("MP3 done\n");

    // Restart ESP when streaming is done or errored
    delay(10000);

    ESP.restart();
  }
  //read events from rotary encoder
  rotary_loop();

}

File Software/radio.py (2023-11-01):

from threading import Thread, Event
import time
import RPi.GPIO as GPIO
from mpd import MPDClient
from RPLCD.i2c import CharLCD
import Encoder

# Threading
lcd_event = Event()
backlight_on_event = Event()
backlight_timeout_event = Event()
backlight_off_event = Event()

# GPIO
nextButton = 4
prevButton = 17
playButton = 25
encoder1 = 23
encoder2 = 24

# MPD
client = MPDClient()
client.timeout = 10
client.idletimeout = None
client.connect("localhost", 6600)
print(client.mpd_version)

# LCD
lcd_string1 = ""
lcd_string2 = ""
LCD_LEN = 16
LCD_MAX_WAIT = 5

lcd = CharLCD(i2c_expander='PCF8574', address=0x27, port=1,
              cols=16, rows=2, dotsize=8,
              charmap='A02',
              auto_linebreaks=False,
              backlight_enabled=True)

# Encoder
enc = Encoder.Encoder(encoder1, encoder2)
old_encoder_value = 0


def PollGpio():

    while True:
        global old_encoder_value
        #encoder_value = enc.read()
        if GPIO.input(nextButton) == False:
            print("Next")
            try:
                backlight_on_event.set()
                client.next()
                client.play()
            except:
                print("Failed")
        elif GPIO.input(prevButton) == False:
            print("Prev")
            try:
                backlight_on_event.set()
                client.previous()
                client.play()
            except:
                print("Failed")
        elif GPIO.input(playButton) == False:
            print("Toggle")
            backlight_on_event.set()
            client.pause()
        #elif encoder_value != old_encoder_value:
        #    print("Volume Change: " + str(encoder_value - old_encoder_value))
        #    client.volume(encoder_value - old_encoder_value)
        #    old_encoder_value = encoder_value
        time.sleep(0.15)


def DataUpdate():
    current_song_title = ""
    current_name = ""
    while True:
        try:
            current_song_title = client.currentsong()["title"]
            print("title: " + str(current_song_title))
        except:
            print("NO title")
        try:
            current_name = str(client.currentsong()["name"])
            print("name: " + current_name)
        except:
            print("NO name")
        print("")
        global lcd_string1
        global lcd_string2
        if current_song_title != lcd_string1:
            lcd_string1 = current_song_title
            lcd_event.set()
        if current_name != lcd_string2:
            lcd_string2 = current_name
        time.sleep(10)


def LcdThread():
    workingstring = ""
    index = 0
    wait = 0
    while True:
        lcd.cursor_pos = (0, 0)
        lcd.write_string(workingstring[index:index+LCD_LEN])
        print(workingstring[index:index+LCD_LEN])
        if lcd_event.is_set():
            lcd_event.clear()
            index = 0
            wait = 0
            workingstring = lcd_string1
        if wait < LCD_MAX_WAIT:
            wait = wait + 1
        elif index >= len(workingstring)-LCD_LEN:
            index = 0
            wait = 0
        else:
            index = index + 1
        if backlight_on_event.is_set():
            backlight_on_event.clear()
            lcd._set_backlight_enabled(True)
            backlight_timeout_event.set()
        if backlight_off_event.is_set():
            backlight_off_event.clear()
            lcd._set_backlight_enabled(False)
        lcd.cursor_pos = (1, 0)
        lcd.write_string(lcd_string2[0:LCD_LEN].ljust(LCD_LEN))

        time.sleep(1)


def BacklightThread():
    while True:
        if backlight_timeout_event.is_set():
            backlight_timeout_event.clear()
            time.sleep(10)
            backlight_off_event.set()


if __name__ == '__main__':
    GPIO.setmode(GPIO.BCM)
    GPIO.setup(nextButton, GPIO.IN, pull_up_down=GPIO.PUD_UP)
    GPIO.setup(prevButton, GPIO.IN, pull_up_down=GPIO.PUD_UP)
    GPIO.setup(playButton, GPIO.IN, pull_up_down=GPIO.PUD_UP)

    lcd.write_string('WLAN Radio')
    lcd.cursor_pos = (1, 0)
    lcd.write_string("1234567890abcdef")

    client.clear()
    client.load("playlist")
    client.play(0)

    polling_thread = Thread(target=PollGpio)
    lcd_thread = Thread(target=LcdThread)
    update_thread = Thread(target=DataUpdate)
    backlight_thread = Thread(target=BacklightThread)
    polling_thread.start()
    lcd_thread.start()
    update_thread.start()
    backlight_thread.start()

    backlight_on_event.set() 

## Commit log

2023-11-01 mpd loops through playlist with buttons
2023-11-02 add pcb
    [WLAN-Radio-HAT.kicad_pcb, WLAN-Radio-HAT.kicad_sch]
2023-11-03 removed unnecessary filter components
    [WLAN-Radio-HAT.kicad_pcb, WLAN-Radio-HAT.kicad_sch]
2023-11-03 add alternate LCD connector and use better 3v3 supply pin
    [WLAN-Radio-HAT.kicad_pcb, WLAN-Radio-HAT.kicad_sch]
2023-11-03 drc corrections
    [WLAN-Radio-HAT.kicad_pcb]
2023-11-05 add case drawing
2023-11-09 add hole for on off switch
2023-11-12 add bom
    [BOM.ods]
2023-11-12 add gerber
2023-11-20 update case svg and add deepenings
2023-12-03 size of screws added to readme
2024-01-29 initial commit for esp32 firmware
